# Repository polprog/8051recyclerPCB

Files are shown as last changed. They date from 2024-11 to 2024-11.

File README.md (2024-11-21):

# 8051recyclerPCB
External memory card for PLCC 8051 OTP processors

PCB designed for recycling OTP PLCC 8051 chips. 

Becasue using the 8051 with external memory burns off most of the ports, I have added two chips that use the external RAM space for an input and output port. Any write to external memory will go to the dedicated output port, and any read from external memory will read the dedicated input port.

(I hope your fine with the in-chip ram :] )

ERRATA (Fixed in revision 2):

- The output chip needs to be 74xx374 or another pin compatible chip but sure the heck not the 74xx373
- Oh, maybe those serial leds ought to be active low eh?
- Could there please be a mark on the common cathode pin of that damn led?
- Could someone please mark the xtal pin for extern clock input?
- Ya know that trace to that top decoupling cap dunn't need to be only 10 thou.

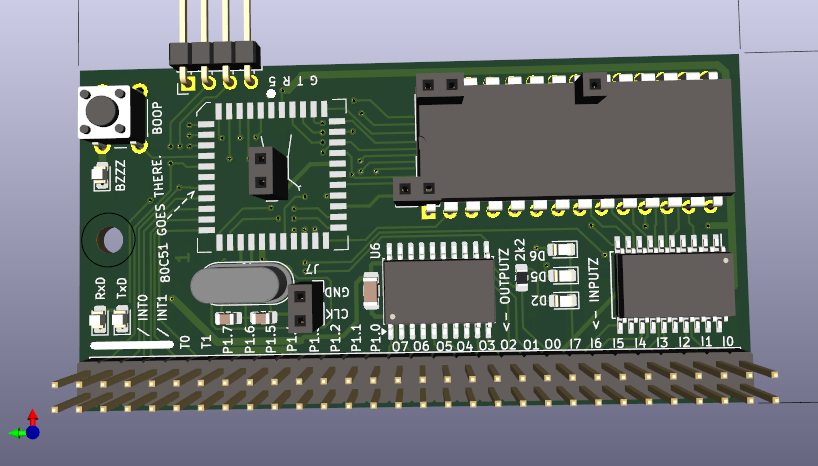
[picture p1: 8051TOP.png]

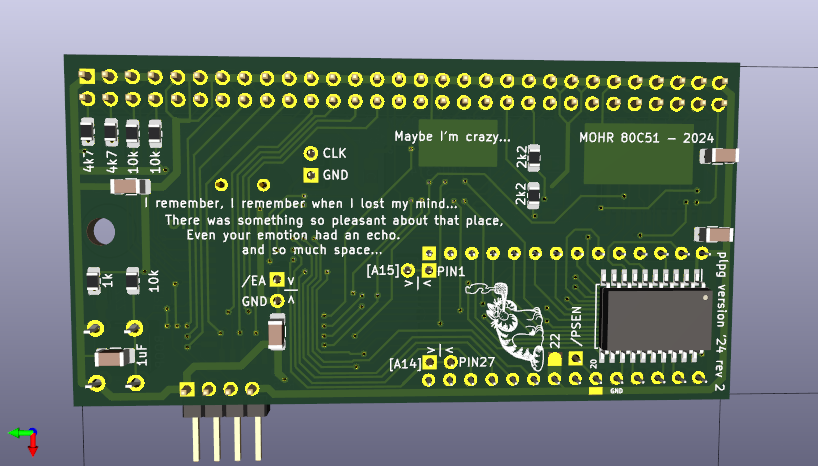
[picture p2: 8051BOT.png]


*not tested yet (oct 2024) *

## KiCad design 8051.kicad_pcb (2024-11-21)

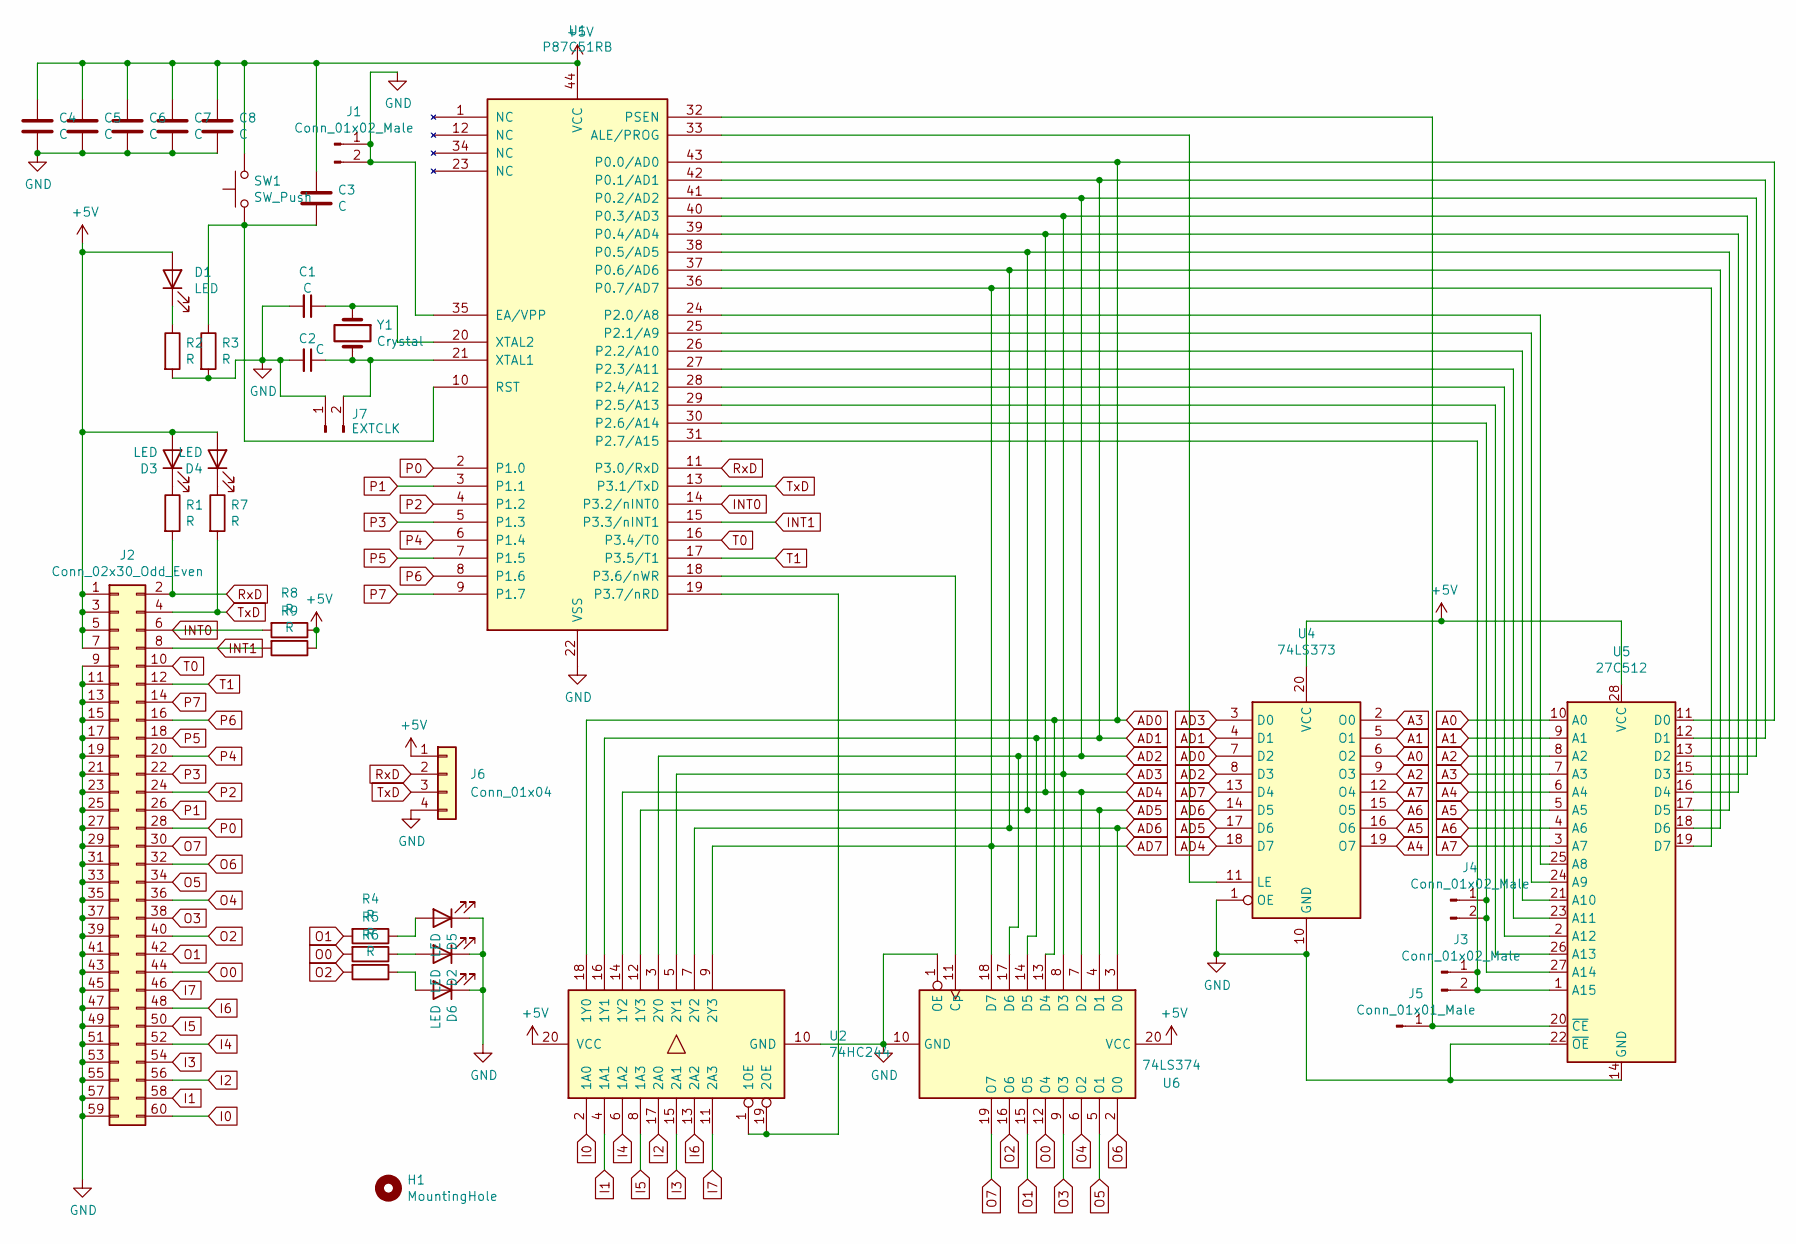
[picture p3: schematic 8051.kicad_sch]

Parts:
C1, C2: C; C_0805_2012Metric_Pad1.15x1.40mm_HandSolder
C3, C4, C5, C6, C7, C8: C; C_1206_3216Metric_Pad1.42x1.75mm_HandSolder
D1, D2, D3, D4, D5, D6: LED; LED_0805_2012Metric_Pad1.15x1.40mm_HandSolder
H1: MountingHole; MountingHole_3.2mm_M3
J1, J3, J4: Conn_01x02_Male; PinSocket_1x02_P2.54mm_Vertical
J2: Conn_02x30_Odd_Even; PinHeader_2x30_P2.54mm_Vertical
J5: Conn_01x01_Male; PinSocket_1x01_P2.54mm_Vertical
J6: Conn_01x04; PinHeader_1x04_P2.54mm_Horizontal
J7: EXTCLK; PinSocket_1x02_P2.54mm_Vertical
R1, R2, R3, R4, R5, R6, R7, R8, R9: R; R_0805_2012Metric_Pad1.15x1.40mm_HandSolder
SW1: SW_Push; SW_PUSH_6mm
U1: P87C51RB; PLCC-44
U2: 74HC244; SOIC-20W_7.5x12.8mm_P1.27mm
U4: 74LS373; SOIC-20W_7.5x12.8mm_P1.27mm
U5: 27C512; DIP-28_W15.24mm
U6: 74LS374; SOIC-20W_7.5x12.8mm_P1.27mm
Y1: Crystal; Crystal_HC49-4H_Vertical

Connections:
+5V: C3.1, C4.1, C5.1, C6.1, C7.1, C8.1, D1.2 (A), D3.2 (A), D4.2 (A), J2.1, J2.3, J2.5, J2.7, J6.1, R8.1, R9.1, SW1.1, U1.44 (VCC), U2.20 (VCC), U4.20 (VCC), U5.28 (VCC), U6.20 (VCC)
A0: U4.6 (O2), U5.10 (A0)
A1: U4.5 (O1), U5.9 (A1)
A2: U4.9 (O3), U5.8 (A2)
A3: U4.2 (O0), U5.7 (A3)
A4: U4.19 (O7), U5.6 (A4)
A5: U4.16 (O6), U5.5 (A5)
A6: U4.15 (O5), U5.4 (A6)
A7: U4.12 (O4), U5.3 (A7)
AD0: U1.43 (P0.0/AD0), U2.18 (1Y0), U4.7 (D2), U5.11 (D0), U6.13 (D4)
AD1: U1.42 (P0.1/AD1), U2.16 (1Y1), U4.4 (D1), U5.12 (D1), U6.14 (D5)
AD2: U1.41 (P0.2/AD2), U2.3 (2Y0), U4.8 (D3), U5.13 (D2), U6.17 (D6)
AD3: U1.40 (P0.3/AD3), U2.5 (2Y1), U4.3 (D0), U5.15 (D3), U6.8 (D3)
AD4: U1.39 (P0.4/AD4), U2.14 (1Y2), U4.18 (D7), U5.16 (D4), U6.7 (D2)
AD5: U1.38 (P0.5/AD5), U2.12 (1Y3), U4.17 (D6), U5.17 (D5), U6.4 (D1)
AD6: U1.37 (P0.6/AD6), U2.7 (2Y2), U4.14 (D5), U5.18 (D6), U6.3 (D0)
AD7: U1.36 (P0.7/AD7), U2.9 (2Y3), U4.13 (D4), U5.19 (D7), U6.18 (D7)
GND: C1.2, C2.2, C4.2, C5.2, C6.2, C7.2, C8.2, D2.1 (K), D5.1 (K), D6.1 (K), J1.1, J1.2, J2.9, J2.11, J2.13, J2.15, J2.17, J2.19, J2.21, J2.23, J2.25, J2.27, J2.29, J2.31, J2.33, J2.35, J2.37, J2.39, J2.41, J2.43, J2.45, J2.47, J2.49, J2.51, J2.53, J2.55, J2.57, J2.59, J6.4, J7.1, R2.2, R3.2, U1.22 (VSS), U1.35 (EA/VPP), U2.10 (GND), U4.1 (OE), U4.10 (GND), U5.14 (GND), U5.22 (~OE), U6.1 (OE), U6.10 (GND)
I0: J2.60, U2.2 (1A0)
I1: J2.58, U2.4 (1A1)
I2: J2.56, U2.17 (2A0)
I3: J2.54, U2.15 (2A1)
I4: J2.52, U2.6 (1A2)
I5: J2.50, U2.8 (1A3)
I6: J2.48, U2.13 (2A2)
I7: J2.46, U2.11 (2A3)
INT0: J2.6, R8.2, U1.14 (P3.2/nINT0)
INT1: J2.8, R9.2, U1.15 (P3.3/nINT1)
unnamed: D1.1 (K), R2.1
unnamed: D2.2 (A), R5.1
unnamed: D3.1 (K), R1.1
unnamed: D4.1 (K), R7.1
unnamed: D5.2 (A), R4.1
unnamed: D6.2 (A), R6.1
unnamed: J3.1, J3.2, U1.31 (P2.7/A15), U5.1 (A15)
unnamed: J4.1, J4.2, U1.30 (P2.6/A14), U5.27 (A14)
unnamed: J5.1, U1.32 (PSEN), U5.20 (~CE)
unnamed: C2.1, J7.2, U1.21 (XTAL1), Y1.2
unnamed: U1.33 (ALE/PROG), U4.11 (LE)
unnamed: U1.24 (P2.0/A8), U5.25 (A8)
unnamed: U1.25 (P2.1/A9), U5.24 (A9)
unnamed: U1.26 (P2.2/A10), U5.21 (A10)
unnamed: U1.27 (P2.3/A11), U5.23 (A11)
unnamed: U1.28 (P2.4/A12), U5.2 (A12)
unnamed: U1.29 (P2.5/A13), U5.26 (A13)
unnamed: U1.18 (P3.6/nWR), U6.11 (Cp)
unnamed: U1.19 (P3.7/nRD), U2.1 (1OE), U2.19 (2OE)
unnamed: C3.2, R3.1, SW1.2, U1.10 (RST)
unnamed: C1.1, U1.20 (XTAL2), Y1.1
O0: J2.44, R5.2, U6.12 (O4)
O1: J2.42, R4.2, U6.15 (O5)
O2: J2.40, R6.2, U6.16 (O6)
O3: J2.38, U6.9 (O3)
O4: J2.36, U6.6 (O2)
O5: J2.34, U6.5 (O1)
O6: J2.32, U6.2 (O0)
O7: J2.30, U6.19 (O7)
P0: J2.28, U1.2 (P1.0)
P1: J2.26, U1.3 (P1.1)
P2: J2.24, U1.4 (P1.2)
P3: J2.22, U1.5 (P1.3)
P4: J2.20, U1.6 (P1.4)
P5: J2.18, U1.7 (P1.5)
P6: J2.16, U1.8 (P1.6)
P7: J2.14, U1.9 (P1.7)
RxD: J2.2, J6.2, R1.2, U1.11 (P3.0/RxD)
T0: J2.10, U1.16 (P3.4/T0)
T1: J2.12, U1.17 (P3.5/T1)
TxD: J2.4, J6.3, R7.2, U1.13 (P3.1/TxD)

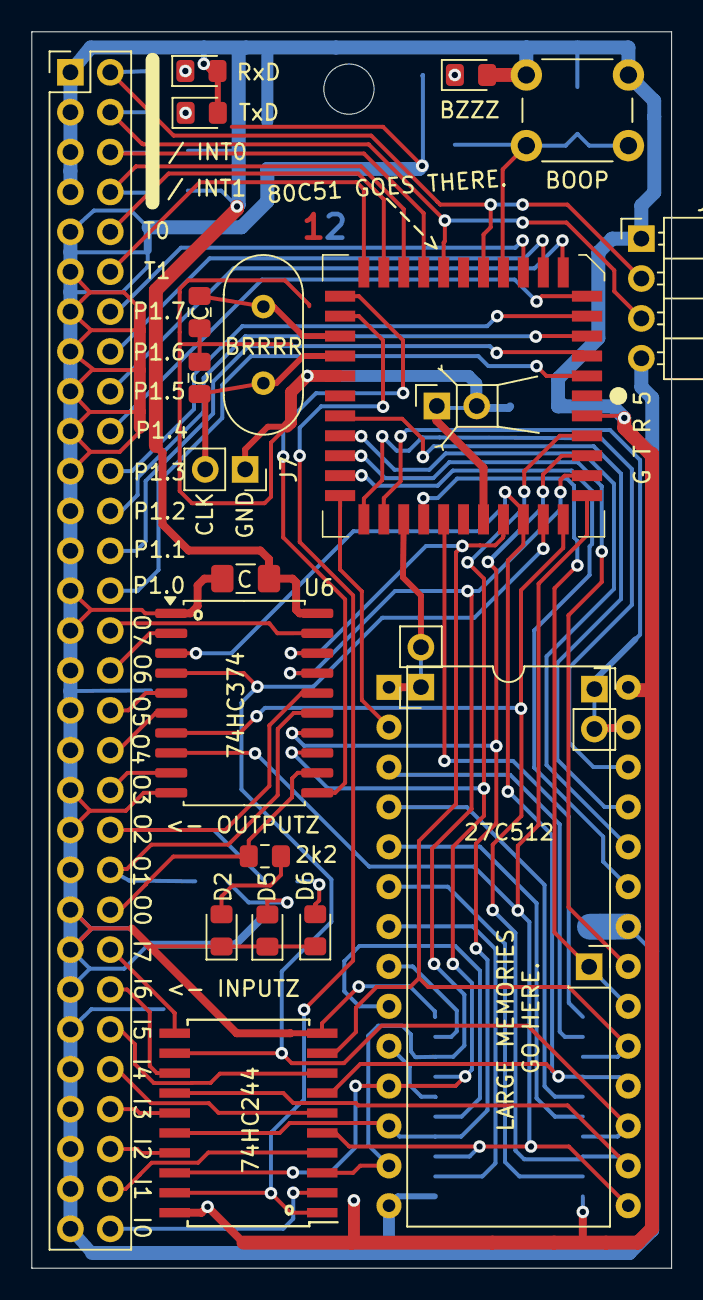
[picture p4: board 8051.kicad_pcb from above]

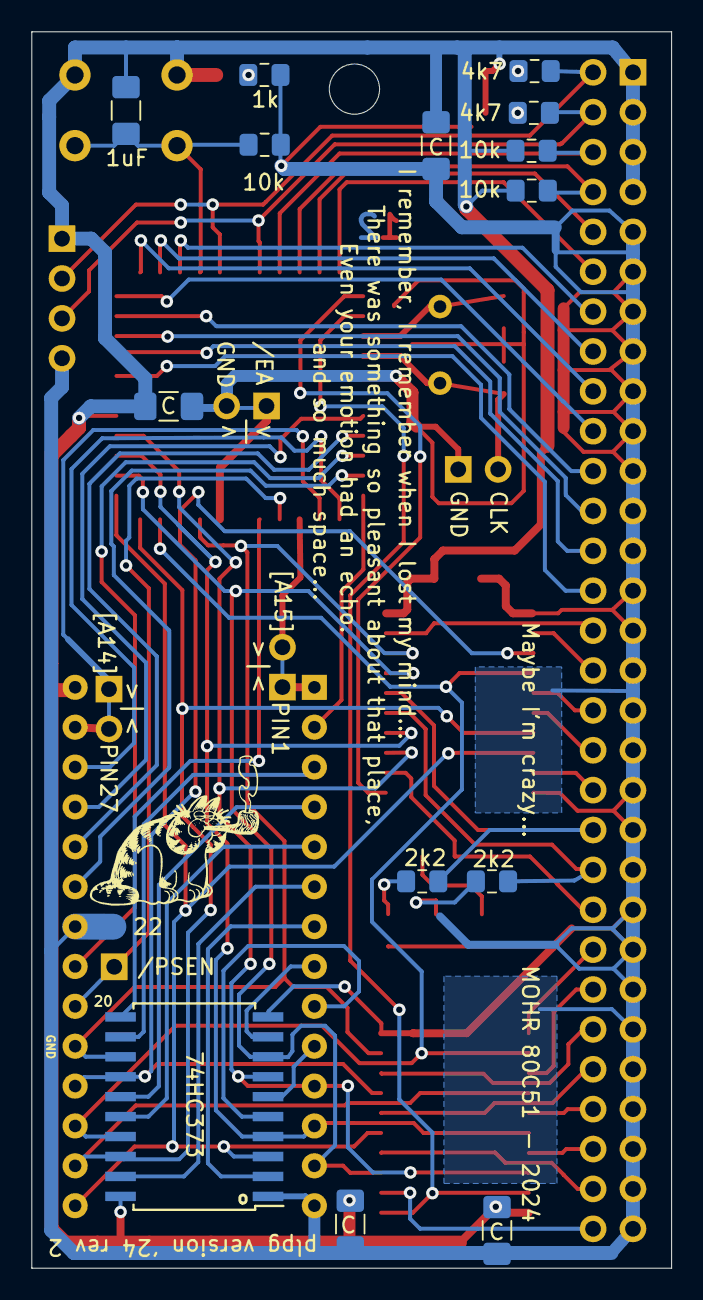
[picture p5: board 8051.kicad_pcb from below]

Board: 2 copper layers, 40.8 x 78.8 mm, 38 parts (14 on the bottom side), 69 nets.

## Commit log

2024-11-02 convert to new Kicad, replace led, add uart header
    [8051.kicad_pcb, 8051.kicad_sch]
2024-11-21 implement rue's errata; update to Kicad 8; revision 2
    [8051.kicad_pcb, 8051.kicad_sch]
2024-11-21 production files
    [8051-B_Cu.gbr, 8051-B_Mask.gbr, 8051-B_Paste.gbr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]
